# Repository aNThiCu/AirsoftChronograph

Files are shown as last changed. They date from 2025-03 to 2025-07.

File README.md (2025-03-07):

# Airsoft Chronograph
A chronograph compatible with ESP32 and ESP8266 used for airsoft to get the exit velocity of the bb from the barrel and RPS of the replica(working on the RPS part).

The default ip for accessing the main webpage should be 192.168.5.5.

A pop-up should appear when u connect to the ESP8266 in AP mode , that is the captive portal which will redirect you to the root page, others are /update(OTA Update)
and /webserial(OTA Serial).

Set your BB weight in the .ino file.

Changing BB weight from the captive portal in progress

An assembly guide of the stl files will come.

Will upload updated 3D models for ESP32 compatibility

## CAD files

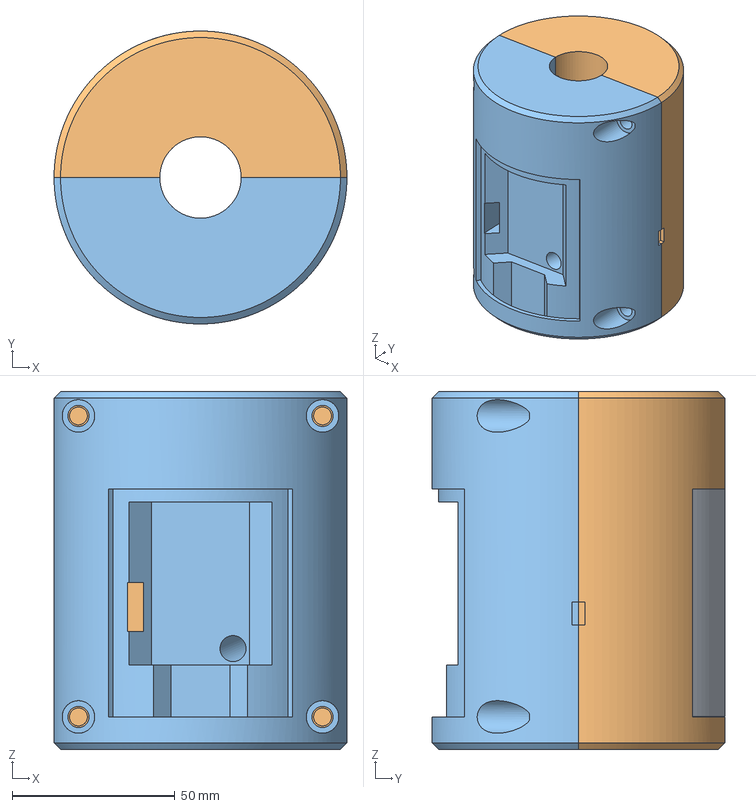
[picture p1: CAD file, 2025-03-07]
3dModels/ESP32/ChronoGraphEsp32.3mf
90.0 x 90.0 x 110.0 mm

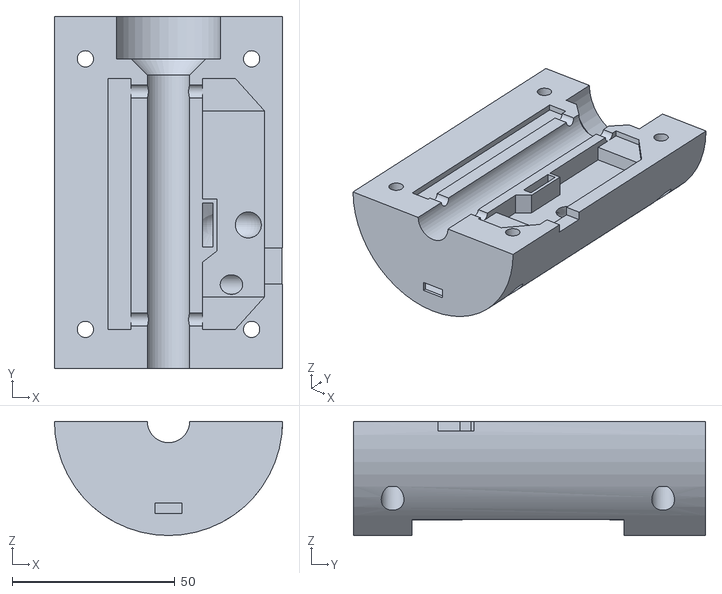
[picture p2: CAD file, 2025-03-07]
3dModels/ESP8266/ChronoESPSide.STL
70.0 x 108.0 x 35.0

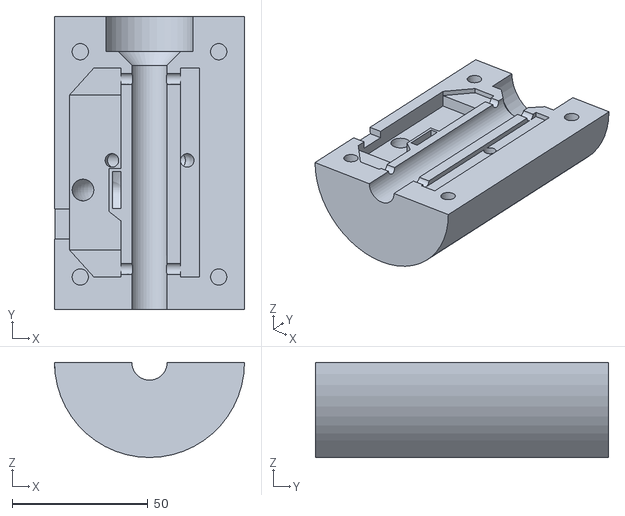
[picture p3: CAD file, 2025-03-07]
3dModels/ESP8266/ChronoSensorSide.STL
70.0 x 108.0 x 35.0

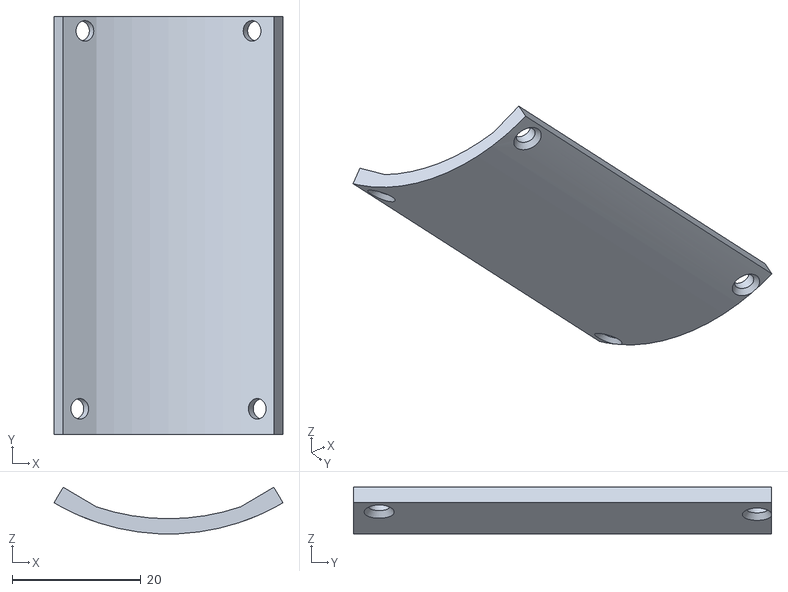
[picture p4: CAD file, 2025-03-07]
3dModels/ESP8266/ChronoESPSideCover.STL
35.6 x 65.0 x 7.24

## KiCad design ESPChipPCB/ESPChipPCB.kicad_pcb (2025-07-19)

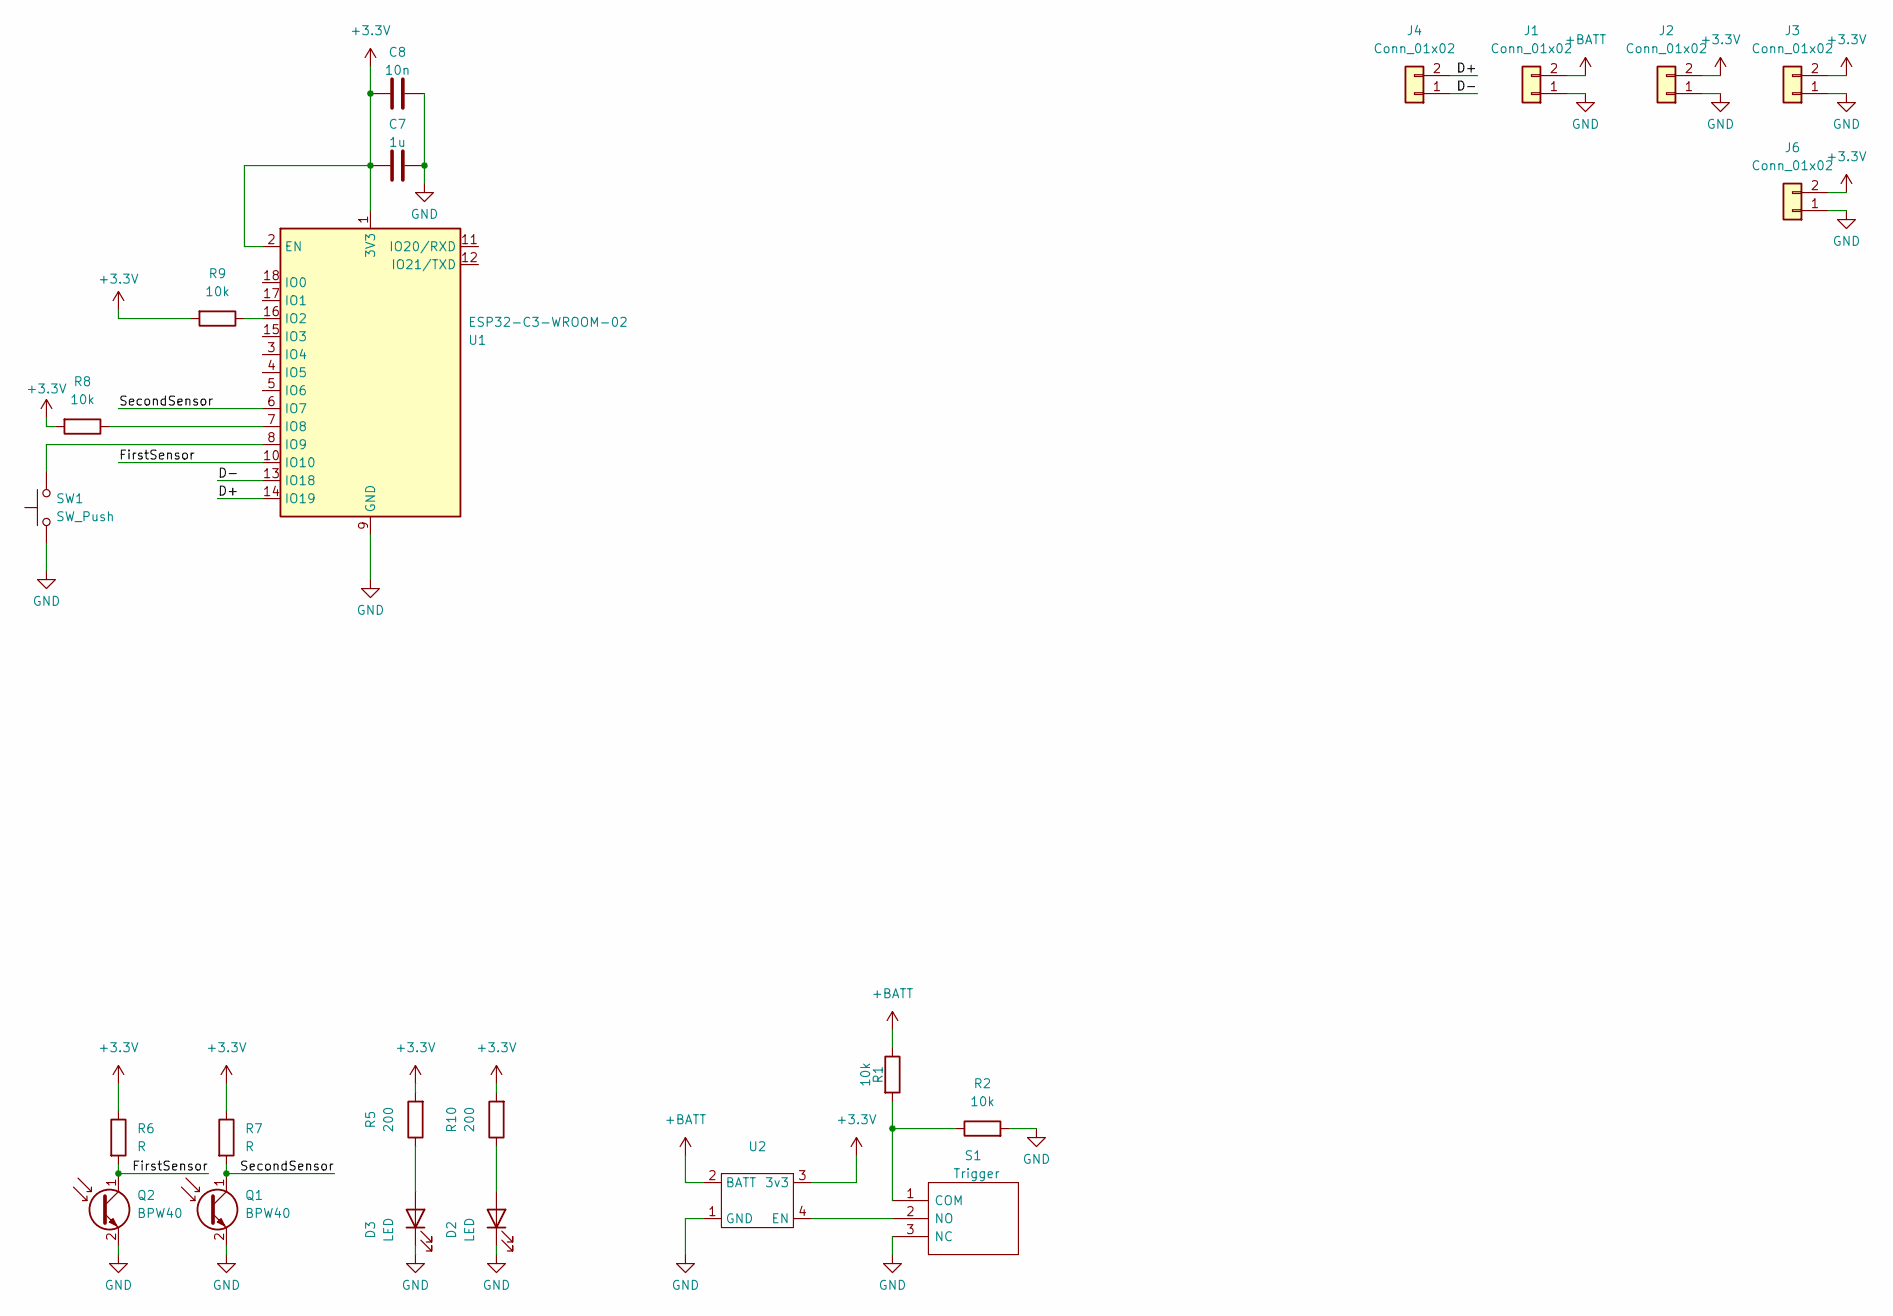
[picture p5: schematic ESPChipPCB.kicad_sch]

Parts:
C7: 1u; C_0603_1608Metric
C8: 10n; C_0603_1608Metric
D2, D3: LED; LED_D5.0mm_Clear
J1, J2, J3, J4, J6: Conn_01x02; PinHeader_1x02_P2.54mm_Vertical
Q1, Q2: BPW40; LED_D5.0mm_Clear
R1, R2, R8, R9: 10k; R_0603_1608Metric
R5, R10: 200; R_0603_1608Metric
R6, R7: R; R_0603_1608Metric
S1: Trigger; SwitchSmall; Mouser Part Number 710-463092691402
SW1: SW_Push; SolderJumper-2_P1.3mm_Open_RoundedPad1.0x1.5mm
U1: ESP32-C3-WROOM-02
U2: StepDown3v3

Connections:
+3.3V: C7.1, C8.1, J2.2, J3.2, J6.2, R5.2, R6.1, R7.1, R8.2, R9.2, R10.2, U1.1 (3V3), U1.2 (EN), U2.3 (3v3)
+BATT: J1.2, R1.1, U2.2 (BATT)
/D+: J4.2, U1.14 (IO19)
/D-: J4.1, U1.13 (IO18)
/FirstSensor: Q2.1 (C), R6.2, U1.10 (IO10)
/SecondSensor: Q1.1 (C), R7.2, U1.6 (IO7)
GND: C7.2, C8.2, D2.1 (K), D3.1 (K), J1.1, J2.1, J3.1, J6.1, Q1.2 (E), Q2.2 (E), R2.2, S1.3 (NC), SW1.1, U1.9 (GND), U1.19 (GND), U2.1 (GND)
unnamed: D2.2 (A), R10.1
unnamed: D3.2 (A), R5.1
unnamed: R1.2, R2.1, S1.1 (COM)
unnamed: S1.2 (NO), U2.4 (EN)
unnamed: R9.1, U1.16 (IO2)
unnamed: R8.1, U1.7 (IO8)
unnamed: SW1.2, U1.8 (IO9)

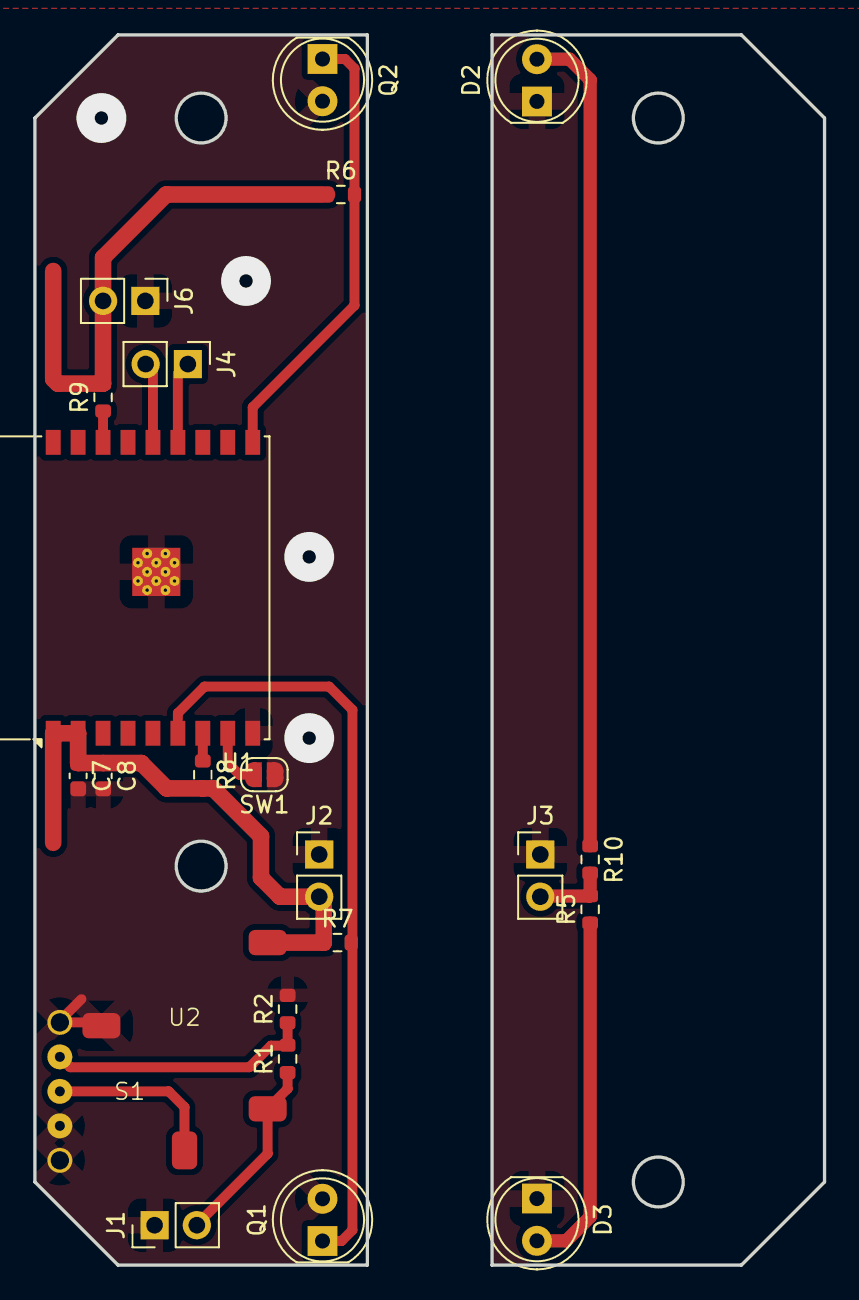
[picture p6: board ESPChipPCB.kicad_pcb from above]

Board: 2 copper layers, 47.5 x 74.0 mm, 23 parts (0 on the bottom side), 14 nets.

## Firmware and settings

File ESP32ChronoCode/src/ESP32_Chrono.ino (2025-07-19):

#define FIRSTSENSOR 10
#define SECONDSENSOR 7

#define TIMESTAMP_QUEUE_SIZE 16 // Can handle up to 16 BBs in flight between sensors
#define BURST_TIMEOUT_MS 1000 // ms to wait after the last shot to finalize RPS calculation
#define DEBOUNCE_TIME_US 200   // 2us debounce

#include <WiFi.h>
#include <Arduino_JSON.h>
#include <ESPAsyncWebServer.h>
#include <DNSServer.h>
#include <AsyncTCP.h>
#include "LittleFS.h"

#include <ElegantOTA.h>
#include <WebSerial.h>
AsyncWebServer webServer(80);
AsyncWebSocket ws("/ws");
DNSServer dnsServer;
const byte DNS_PORT = 53;

// Circular queue for timestamps from the first sensor (in microseconds)
volatile unsigned long first_sensor_ts_us[TIMESTAMP_QUEUE_SIZE];//timestamps
volatile int ts_queue_head = 0;
volatile int ts_queue_tail = 0;

// Circular queue for completed shot travel times (in microseconds)
volatile unsigned long completed_shot_t_us[TIMESTAMP_QUEUE_SIZE];//time between sensors
volatile int completed_queue_head = 0;
volatile int completed_queue_tail = 0;

// Volatile variables for RPS calculation, modified by ISR
volatile int shot_count = 0;
volatile unsigned long first_shot_ts_us = 0;
volatile unsigned long last_shot_ts_us = 0;

// Debouncing variables
volatile unsigned long last_ts_entry_us = 0;
volatile unsigned long last_ts_exit_us = 0;

// Settings
float DISTANCEACROSS = 67.75;
float BBWEIGHT = 0.28;
// End Settings

// --- Global State for Burst Calculation ---
float speed_accumulator = 0;
float energy_accumulator = 0;

// --- Debugging ---
#define DEBUG_QUEUE_SIZE 32
volatile unsigned long debug_queue_1[DEBUG_QUEUE_SIZE];
volatile int debug_q1_head = 0;
volatile int debug_q1_tail = 0;

volatile unsigned long debug_queue_2[DEBUG_QUEUE_SIZE];
volatile int debug_q2_head = 0;
volatile int debug_q2_tail = 0;
// --- End Debugging ---

// --- End Global State ---



void IRAM_ATTR getFirstSensor() {
  unsigned long now_us = micros();
  // --- Debugging: Log raw timestamp to its dedicated queue (lock-free) ---
  int next_head = (debug_q1_head + 1) % DEBUG_QUEUE_SIZE;
  if (next_head != debug_q1_tail) {
    debug_queue_1[debug_q1_head] = now_us;
    debug_q1_head = next_head;
  }
  // --- End Debugging ---

  if (now_us - last_ts_entry_us < DEBOUNCE_TIME_US) return;

  last_ts_entry_us = now_us;

  next_head = (ts_queue_head + 1) % TIMESTAMP_QUEUE_SIZE;
  if (next_head == ts_queue_tail) return; // Queue is full, drop shot

  first_sensor_ts_us[ts_queue_head] = now_us;
  ts_queue_head = next_head;
}

void IRAM_ATTR getSecondSensor() {
  unsigned long now_us = micros();
  // --- Debugging: Log raw timestamp to its dedicated queue (lock-free) ---
  int next_head = (debug_q2_head + 1) % DEBUG_QUEUE_SIZE;
  if (next_head != debug_q2_tail) {
    debug_queue_2[debug_q2_head] = now_us;
    debug_q2_head = next_head;
  }
  // --- End Debugging ---

  if (now_us - last_ts_exit_us < DEBOUNCE_TIME_US) return;

  last_ts_exit_us = now_us;

  if (ts_queue_head == ts_queue_tail) return; // Spurious trigger

  unsigned long first_ts = first_sensor_ts_us[ts_queue_tail];
  ts_queue_tail = (ts_queue_tail + 1) % TIMESTAMP_QUEUE_SIZE;

  unsigned long travel_time_us = now_us - first_ts;
  
  int next_completed_head = (completed_queue_head + 1) % TIMESTAMP_QUEUE_SIZE;
  if (next_completed_head == completed_queue_tail) return; // Completed queue full
  
  completed_shot_t_us[completed_queue_head] = travel_time_us;
  completed_queue_head = next_completed_head;

  if (shot_count == 0) first_shot_ts_us = now_us;
  last_shot_ts_us = now_us;
  shot_count++;
}

// --- End of Chronograph Logic ---

void initPins() {
  pinMode(FIRSTSENSOR, INPUT);
  pinMode(SECONDSENSOR, INPUT);
  Serial.println("Sensors Initialized with internal pull-ups");
}

void initLittleFS() {
  if (!LittleFS.begin()) {
    Serial.println("An error has occurred while mounting LittleFS");
  }
  Serial.println("LittleFS mounted successfully");
}

void initWiFi() {
  WiFi.mode(WIFI_AP);
  WiFi.softAP("Chronograph");
  Serial.println("WiFi Initialized");
}

void initNetwork() {
  dnsServer.start(DNS_PORT, "*", WiFi.softAPIP());
  webServer.on("/", HTTP_GET, [](AsyncWebServerRequest *request){
    request->send(LittleFS, "/index.html", "text/html");
  });
  webServer.on("/style.css", HTTP_GET, [](AsyncWebServerRequest *request){
    request->send(LittleFS, "/style.css", "text/css");
  });
  webServer.on("/script.js", HTTP_GET, [](AsyncWebServerRequest *request){
    request->send(LittleFS, "/script.js", "application/javascript");
  });
  webServer.onNotFound([](AsyncWebServerRequest *request){
    request->redirect("/");
  });

  ElegantOTA.begin(&webServer);
  ws.onEvent(onEvent);
  webServer.addHandler(&ws);
  webServer.begin();
  Serial.println("Captive Portal Initialized");
}

void initInterrupts() {
  attachInterrupt(digitalPinToInterrupt(FIRSTSENSOR), getFirstSensor, RISING);
  attachInterrupt(digitalPinToInterrupt(SECONDSENSOR), getSecondSensor, RISING);
  Serial.println("Interrupts Initialized");
}

void handleWebSocketMessage(void *arg, uint8_t *data, size_t len) {
  AwsFrameInfo *info = (AwsFrameInfo *)arg;
  if (info->final && info->index == 0 && info->len == len && info->opcode == WS_TEXT) {
    data[len] = 0;
    JSONVar receivedData = JSON.parse((char*)data);

    if (JSON.typeof(receivedData) == "undefined") {
      Serial.println("Parsing input failed!");
      return;
    }
    if (receivedData.hasOwnProperty("bbWeight")) {
      BBWEIGHT = (double)receivedData["bbWeight"];
      Serial.print("Updated BB Weight to: ");
      Serial.println(BBWEIGHT);
    }
    if (receivedData.hasOwnProperty("distanceAcross")) {
      DISTANCEACROSS = (double)receivedData["distanceAcross"];
      Serial.print("Updated Sensor Distance to: ");
      Serial.println(DISTANCEACROSS);
    }
  }
}

void onEvent(AsyncWebSocket *server, AsyncWebSocketClient *client, AwsEventType type, void *arg, uint8_t *data, size_t len) {
  switch (type) {
    case WS_EVT_CONNECT:{
      Serial.printf("WebSocket client #%u connected from %s\n", client->id(), client->remoteIP().toString().c_str());
      JSONVar settings;
      settings["bbWeight"] = BBWEIGHT;
      settings["distanceAcross"] = DISTANCEACROSS;
      client->text(JSON.stringify(settings));
      break;}
    case WS_EVT_DISCONNECT:{
      Serial.printf("WebSocket client #%u disconnected\n", client->id());
      break;}
    case WS_EVT_DATA:{
      handleWebSocketMessage(arg, data, len);
      break;}
    case WS_EVT_PONG: {break;}
    case WS_EVT_ERROR:{break;}
  }
}

void setup() {
  Serial.begin(115200);
  initPins();
  initWiFi();
  initLittleFS();
  initNetwork();
  initInterrupts();
}

String packData(const float* speed, const float* energy, const float* rps, const float* avg_speed, const float* avg_energy) {
  JSONVar data;
  if (speed) data["metric"] = *speed;
  if (energy) data["joules"] = *energy;
  if (rps) data["rps"] = *rps;
  if (avg_speed) data["avg_metric"] = *avg_speed;
  if (avg_energy) data["avg_joules"] = *avg_energy;
  return JSON.stringify(data);
}

void calculateSpeed(){
  if (completed_queue_head != completed_queue_tail) {

    unsigned long travel_time_us = completed_shot_t_us[completed_queue_tail];
    completed_queue_tail = (completed_queue_tail + 1) % TIMESTAMP_QUEUE_SIZE;

    float speed = 0, energy = 0;
    float travel_time_s = (travel_time_us * 1.0) / 1000000.0;

    if (travel_time_s > 0) {
      speed = (DISTANCEACROSS / 1000.0) / travel_time_s;
      energy = (BBWEIGHT / 2000.0) * speed * speed;
    }

    ws.textAll(packData(&speed, &energy, nullptr, nullptr, nullptr));

    speed_accumulator += speed;
    energy_accumulator += energy;
  }
}


void resetVariables(){
    speed_accumulator = 0;
    energy_accumulator = 0;
    shot_count = 0;

    noInterrupts();
    ts_queue_head = ts_queue_tail;
    completed_queue_head = completed_queue_tail;
    interrupts();
}

void calculateRPS(){

  int saved_shot_count = shot_count;
  unsigned long saved_last_shot = last_shot_ts_us;
  bool is_queue_empty = (completed_queue_head == completed_queue_tail);

  if (saved_shot_count > 0 && is_queue_empty && (micros() - saved_last_shot > BURST_TIMEOUT_MS * 1000ULL)) {
   
    if (saved_shot_count > 1) {
        float rounds_per_second = 0;
        unsigned long saved_first_shot = first_shot_ts_us;
        unsigned long burst_duration_us = saved_last_shot - saved_first_shot;
        if (burst_duration_us > 0) rounds_per_second = (float)(saved_shot_count - 1) * 1000000.0 / burst_duration_us;
        
        float avg_speed = speed_accumulator / saved_shot_count;
        float avg_energy = energy_accumulator / saved_shot_count;

        ws.textAll(packData(nullptr, nullptr, &rounds_per_second, &avg_speed, &avg_energy));
    }
    
    resetVariables();
  }
}

void processData() {
  calculateSpeed();
  calculateRPS();
}

void processDebugQueues(){
  // Process Sensor 1 debug queue
  if (debug_q1_head != debug_q1_tail) {
    unsigned long ts = debug_queue_1[debug_q1_tail];
    debug_q1_tail = (debug_q1_tail + 1) % DEBUG_QUEUE_SIZE;
    String msg = "Sensor 1: " + String(ts);
    JSONVar data;
    data["debug"] = msg;
    ws.textAll(JSON.stringify(data));
  }

  // Process Sensor 2 debug queue
  if (debug_q2_head != debug_q2_tail) {
    unsigned long ts = debug_queue_2[debug_q2_tail];
    debug_q2_tail = (debug_q2_tail + 1) % DEBUG_QUEUE_SIZE;
    String msg = "Sensor 2: " + String(ts);
    JSONVar data;
    data["debug"] = msg;
    ws.textAll(JSON.stringify(data));
  }
}

void loop() {
  dnsServer.processNextRequest();
  ws.cleanupClients();
  processData();
  processDebugQueues();
}

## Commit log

2025-03-07 added models for ESP32
    [ChronoESPSide.STL, ChronoESPSideCover.STL, ChronoGraphEsp32.3mf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]
2025-03-10 started development on PCB version
    [ESPChipPCB.kicad_pcb, ESPChipPCB.kicad_sch]
2025-07-02 More pcb stuff
    [ESPChipPCB.kicad_pcb, ESPChipPCB.kicad_sch, ESPChipPCB_Controller.step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]
2025-07-15 Moved from arduino to platformio , redone some of the code
    [ESPChipPCB.kicad_pcb, ESPChipPCB.kicad_sch, ESPChipPCB_Controller.step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]
2025-07-19 Redone logic and calculations
    [ESPChipPCB.kicad_pcb, ESPChipPCB.kicad_sch]
